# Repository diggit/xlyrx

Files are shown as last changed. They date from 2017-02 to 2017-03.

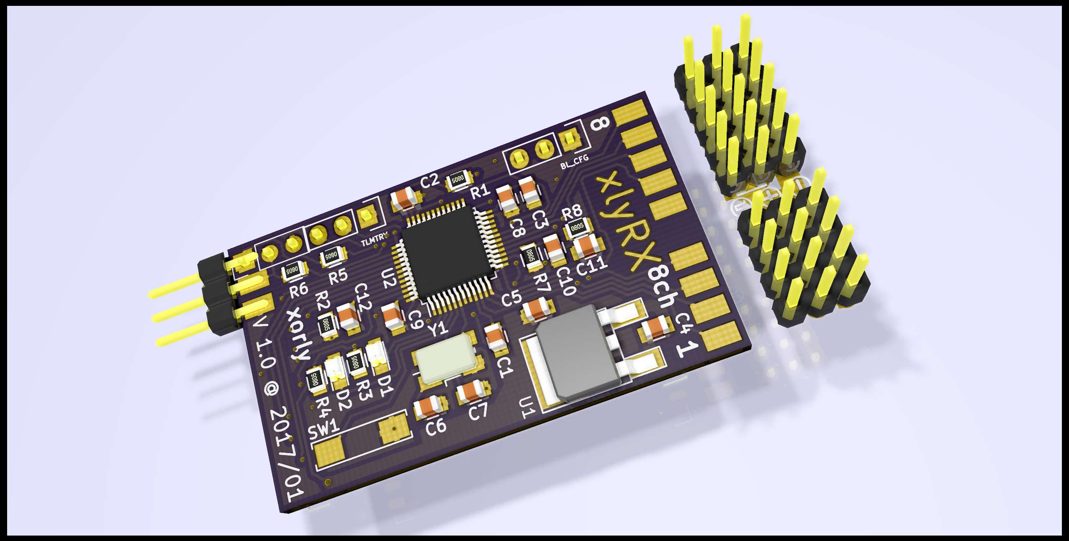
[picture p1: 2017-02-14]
design/pcb/xlyRX.png

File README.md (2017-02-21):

# xlyrx
Hobby RC 2.4GHz receiver based on cc2500 and STM32, supporting FrSky 2 Way D-series protocol

This project is another opensource receiver for cc2500 based radios.

## Features
- FrSky 2-way (telemetry) protocol for D-series
- based on ARM MCU (STM32)
- Hardware generated high resolution ppm signal (~4 times higher, than FrSky can tranfer)
- bind time RX-TX frequency offset elimination
- high power power amplifier and high sensitivity low noise amplifier cc2500 module
- alternative power input for channels 5,6,7,8
- 2 analog inputs
- initial work on fail-safes, when signal is lost, outputs are tuned off now, user config is missing

*ready, but hardcoded for now*
- configurable ppm frequency
	- channels 1,2,5,6 are driven by one HW timer, outputs 4,5,7,8 are driven by another
	- ppm frequency is defined by 3rd timer, all channels have same frequency for now, to be able to have different ppm frequency for each group, packet timeout timer must be changed from regular timer to systick, then we'll have free HW timer to drive second group of outputs with different frequency

*HW ready, SW not yet written*
- UART (3,3V) for loading new firmware (bootloader) and RX user configuration
- UART (3,3V) for external telemetry configuration (raw or FrSky format)
- meaningful usage of LED (we have 2 of them, so use them!)

### Known issues
- if TX and RX are too close during binding, binding may not be successful (stuck in binding mode)
	- maybe some AGC tuning could help
	- workaround would be binding procedure restart

## Why?
If you sum up all that time, materials and work, why (I) build this and not buy regular FrSky receiver? For fun! To explore HW, skills... I like the possibility to modify things to way I like them. Easily add new features and make them better than regular ones...

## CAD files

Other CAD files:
design/case/housing.fcstd

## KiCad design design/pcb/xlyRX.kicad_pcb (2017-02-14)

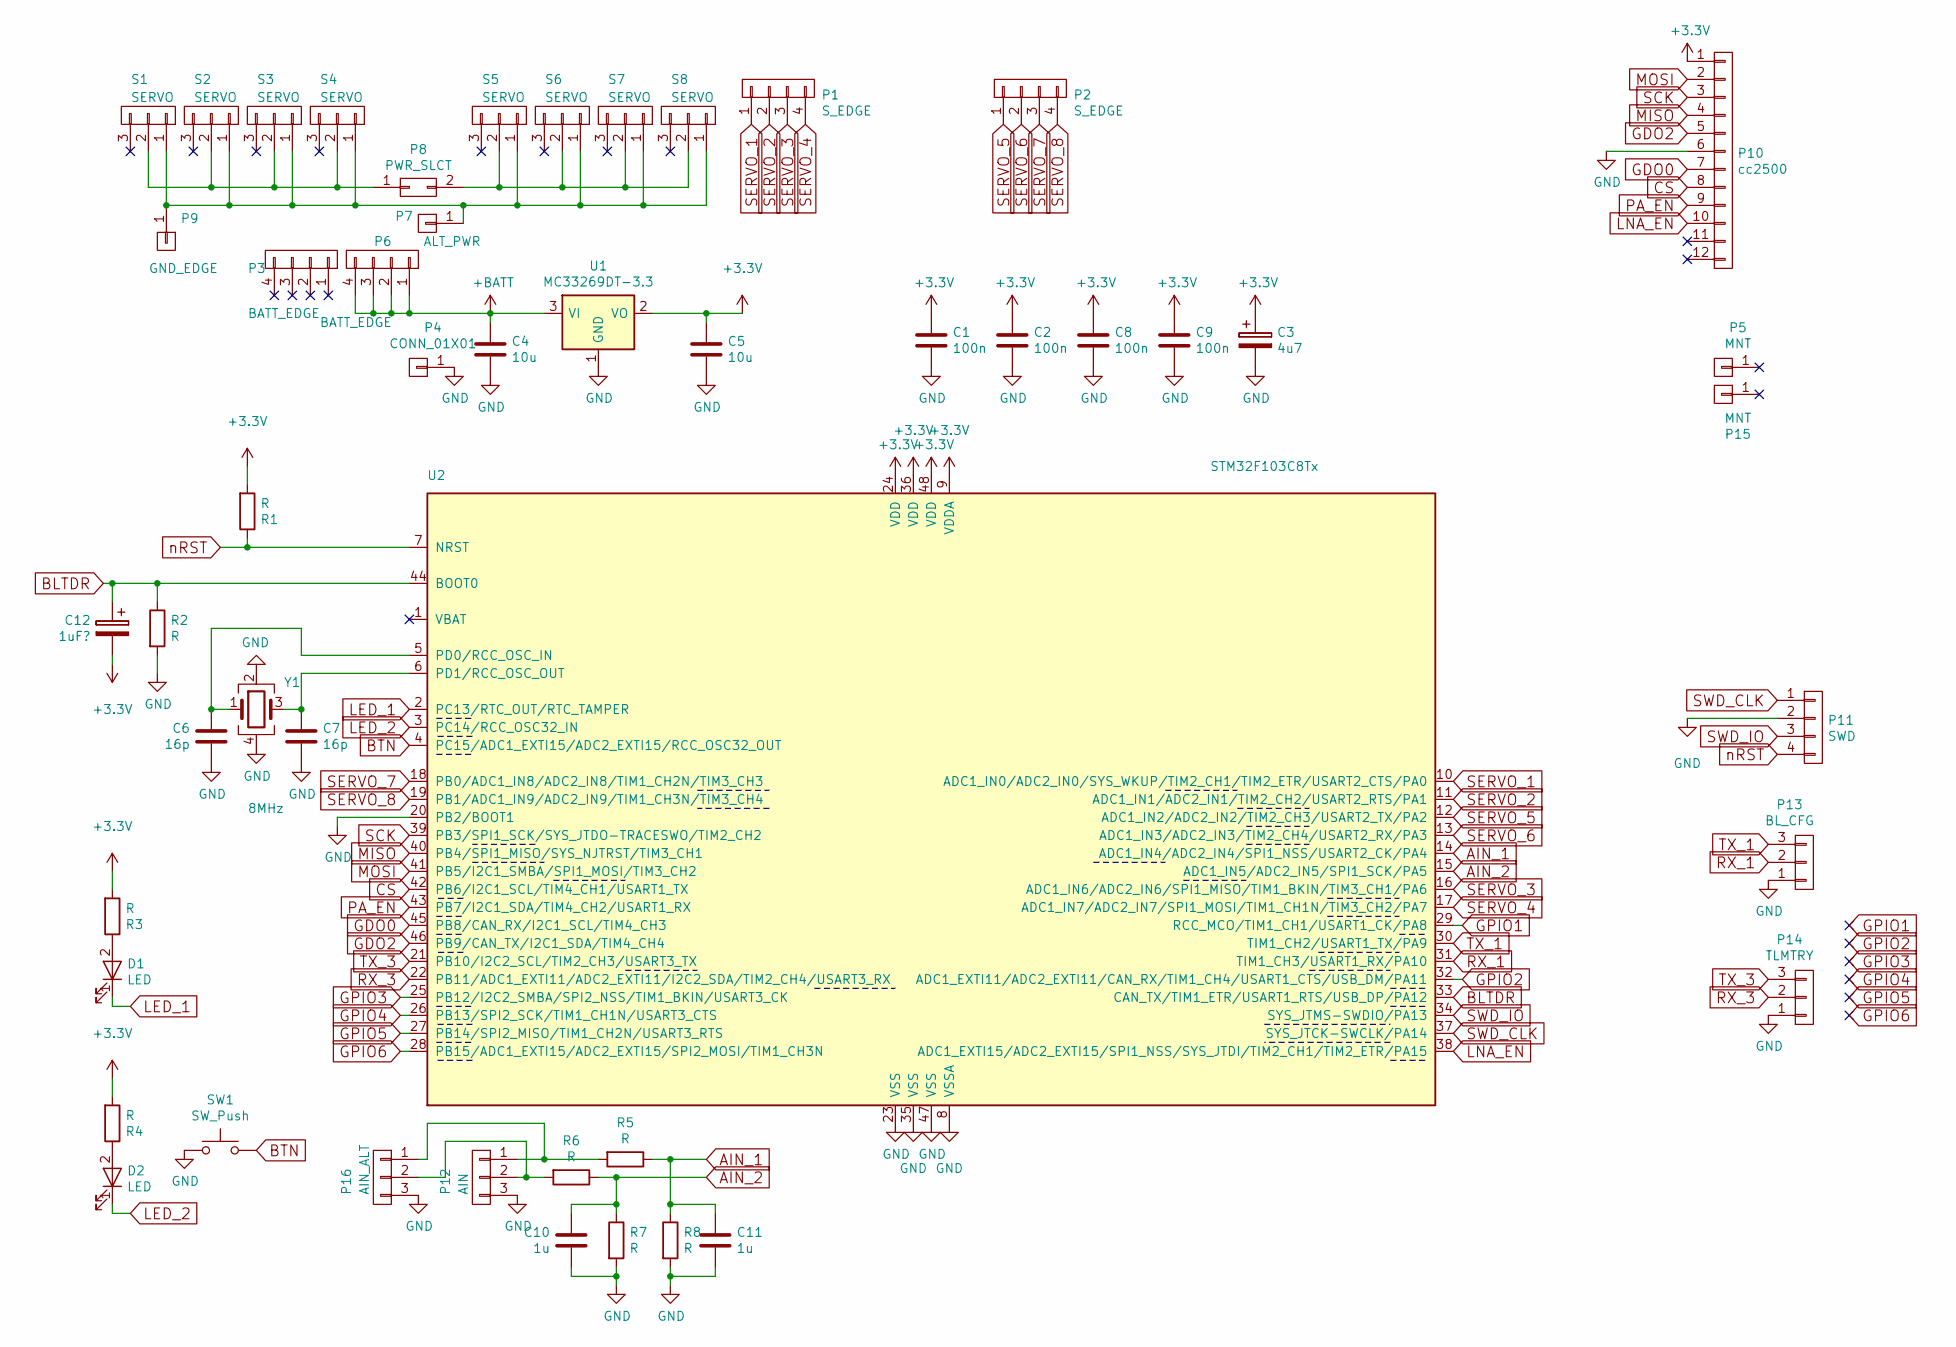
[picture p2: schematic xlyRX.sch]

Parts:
C1, C2, C8, C9: 100n; C_0805
C3: 4u7; C_0805
C4, C5: 10u; C_0805
C6, C7: 16p; C_0805
C10, C11: 1u; C_0805
C12: 1uF?; C_0805
D1, D2: LED; LED_0805
P1, P2: S_EDGE; SMD_conn_edge
P3, P6: BATT_EDGE; SMD_conn_edge
P4: CONN_01X01; SMD_conn_edge_1p
P5, P15: MNT; SMD_conn_edge_1p
P7: ALT_PWR; Pin_Header_Straight_1x01_Pitch2.54mm_simplified_silk
P8: PWR_SLCT; Pin_Header_Straight_1x02_Pitch2.54mm_simplified_silk
P9: GND_EDGE; SMD_conn_edge_1p
P10: cc2500; module_cc2500_PA_LNA_small_pads
P11: SWD; SMD_conn_edge
P12: AIN; SMD_conn_edge_3
P13: BL_CFG; Pin_Header_Straight_1x03
P14: TLMTRY; Pin_Header_Straight_1x03
P16: AIN_ALT; Pin_Header_Straight_1x03_Pitch2.54mm
R1, R2, R3, R4, R5, R6, R7, R8: R; R_0805
S1, S2, S3, S4, S5, S6, S7, S8: SERVO; Pin_Header_Straight_1x03_Pitch2.54mm_simplified_silk
SW1: SW_Push; SW_SPST_REED_CT05-XXXX-J1
U1: MC33269DT-3.3; TO-252-2Lead
U2: STM32F103C8Tx; LQFP-48_7x7mm_Pitch0.5mm
Y1: 8MHz; Crystal_SMD_5032_4Pads

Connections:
+3V3: C1.1, C2.1, C3.1, C5.1, C8.1, C9.1, C12.2, P10.1, R1.2, R3.2, R4.2, U1.2 (VO), U2.9 (VDDA), U2.24 (VDD), U2.36 (VDD), U2.48 (VDD)
+BATT: C4.1, P6.1, P6.2, P6.3, P6.4, U1.3 (VI)
AIN_1: C11.1, R5.1, R8.1, U2.14 (ADC1_IN4/ADC2_IN4/SPI1_NSS/USART2_CK/PA4)
AIN_2: C10.1, R6.1, R7.1, U2.15 (ADC1_IN5/ADC2_IN5/SPI1_SCK/PA5)
BLTDR: C12.1, R2.1, U2.33 (CAN_TX/TIM1_ETR/USART1_RTS/USB_DP/PA12), U2.44 (BOOT0)
BTN: SW1.2, U2.4 (PC15/ADC1_EXTI15/ADC2_EXTI15/RCC_OSC32_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)
CS: P10.8, U2.42 (PB6/I2C1_SCL/TIM4_CH1/USART1_TX)
GDO0: P10.7, U2.45 (PB8/CAN_RX/I2C1_SCL/TIM4_CH3)
GDO2: P10.5, U2.46 (PB9/CAN_TX/I2C1_SDA/TIM4_CH4)
GND: C1.2, C2.2, C3.2, C4.2, C5.2, C6.2, C7.2, C8.2, C9.2, C10.2, C11.2, P4.1, P10.6, P11.2, P12.3, P13.1, P14.1, P16.3, R2.2, R7.2, R8.2, SW1.1, U1.1 (GND), U2.8 (VSSA), U2.20 (PB2/BOOT1), U2.23 (VSS), U2.35 (VSS), U2.47 (VSS), Y1.2, Y1.4
GPIO1: U2.29 (RCC_MCO/TIM1_CH1/USART1_CK/PA8)
GPIO2: U2.32 (ADC1_EXTI11/ADC2_EXTI11/CAN_RX/TIM1_CH4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)
GPIO3: U2.25 (PB12/I2C2_SMBA/SPI2_NSS/TIM1_BKIN/USART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)
GPIO4: U2.26 (PB13/SPI2_SCK/TIM1_CH1N/USART3_CTS)
GPIO5: U2.27 (PB14/SPI2_MISO/TIM1_CH2N/USART3_RTS)
GPIO6: U2.28 (PB15/ADC1_EXTI15/ADC2_EXTI15/SPI2_MOSI/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)
LED_1: D1.1 (K), U2.2 (PC13/RTC_OUT/RTC_TAMPER)
LED_2: D2.1 (K), U2.3 (PC14/RCC_OSC32_IN)
LNA_EN: P10.10, U2.38 (ADC1_EXTI15/ADC2_EXTI15/SPI1_NSS/SYS_JT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)
MISO: P10.4, U2.40 (PB4/SPI1_MISO/SYS_NJTRST/TIM3_CH1)
MOSI: P10.2, U2.41 (PB5/I2C1_SMBA/SPI1_MOSI/TIM3_CH2)
unnamed: C6.1, U2.5 (PD0/RCC_OSC_IN), Y1.1
unnamed: C7.1, U2.6 (PD1/RCC_OSC_OUT), Y1.3
unnamed: D1.2 (A), R3.1
unnamed: D2.2 (A), R4.1
unnamed: P7.1, P9.1, S1.1, S2.1, S3.1, S4.1, S5.1, S6.1, S7.1, S8.1
unnamed: P8.1, S1.2, S2.2, S3.2, S4.2
unnamed: P8.2, S5.2, S6.2, S7.2, S8.2
unnamed: P12.1, P16.1, R5.2
unnamed: P12.2, P16.2, R6.2
PA_EN: P10.9, U2.43 (PB7/I2C1_SDA/TIM4_CH2/USART1_RX)
RX_1: P13.2, U2.31 (TIM1_CH3/USART1_RX/PA10)
RX_3: P14.2, U2.22 (PB11/ADC1_EXTI11/ADC2_EXTI11/I2C2_SDA/T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)
SCK: P10.3, U2.39 (PB3/SPI1_SCK/SYS_JTDO-TRACESWO/TIM2_CH2)
SERVO_1: P1.1, U2.10 (ADC1_IN0/ADC2_IN0/SYS_WKUP/TIM2_CH1/TIM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)
SERVO_2: P1.2, U2.11 (ADC1_IN1/ADC2_IN1/TIM2_CH2/USART2_RTS/P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)
SERVO_3: P1.3, U2.16 (ADC1_IN6/ADC2_IN6/SPI1_MISO/TIM1_BKIN/T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)
SERVO_4: P1.4, U2.17 (ADC1_IN7/ADC2_IN7/SPI1_MOSI/TIM1_CH1N/T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)
SERVO_5: P2.1, U2.12 (ADC1_IN2/ADC2_IN2/TIM2_CH3/USART2_TX/PA2)
SERVO_6: P2.2, U2.13 (ADC1_IN3/ADC2_IN3/TIM2_CH4/USART2_RX/PA3)
SERVO_7: P2.3, U2.18 (PB0/ADC1_IN8/ADC2_IN8/TIM1_CH2N/TIM3_CH3)
SERVO_8: P2.4, U2.19 (PB1/ADC1_IN9/ADC2_IN9/TIM1_CH3N/TIM3_CH4)
SWD_CLK: P11.1, U2.37 (SYS_JTCK-SWCLK/PA14)
SWD_IO: P11.3, U2.34 (SYS_JTMS-SWDIO/PA13)
TX_1: P13.3, U2.30 (TIM1_CH2/USART1_TX/PA9)
TX_3: P14.3, U2.21 (PB10/I2C2_SCL/TIM2_CH3/USART3_TX)
nRST: P11.4, R1.1, U2.7 (NRST)

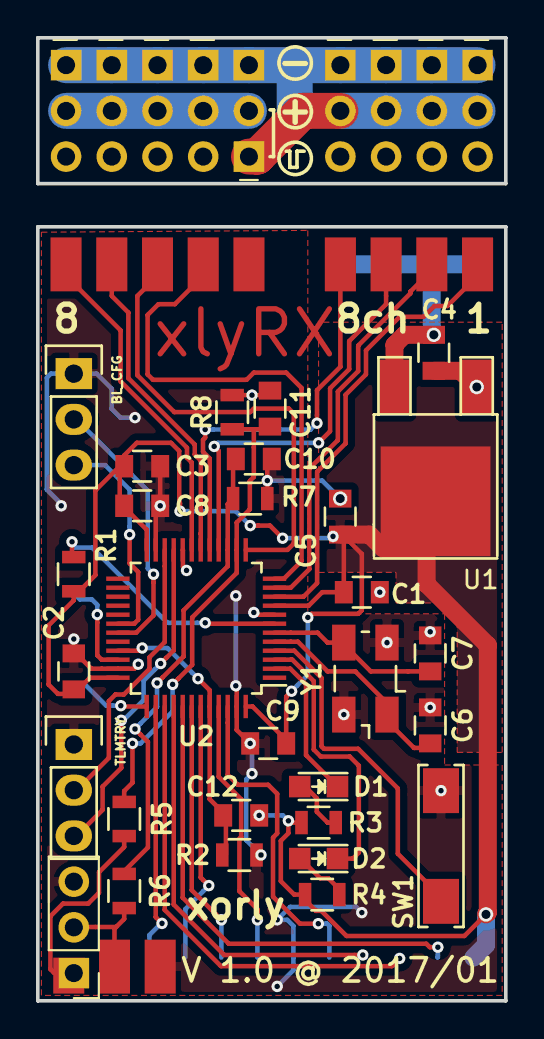
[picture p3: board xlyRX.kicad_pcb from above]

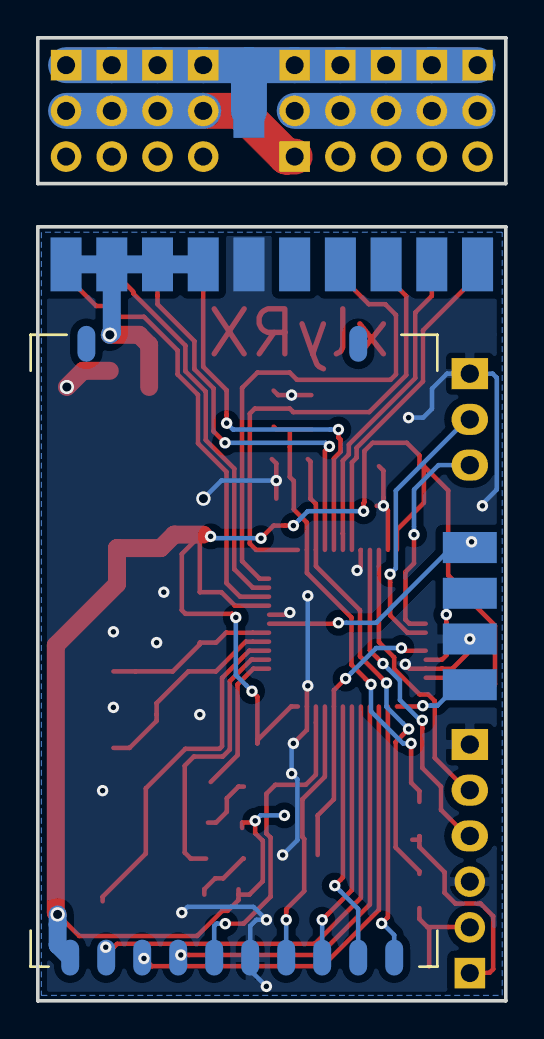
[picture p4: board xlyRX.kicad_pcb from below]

Board: 2 copper layers, 26.0 x 53.5 mm, 50 parts (7 on the bottom side), 41 nets.

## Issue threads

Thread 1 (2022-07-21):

Getting stucked in calibration

satyagupta, 2022-07-21:
Thanks for this fantastic code base. I am trying to rebuild a diy frsky receiver based on your frimware. Based on very little documentation and resources for CC2500 i really appreciate the efforts you have taken to write this firmware.

What is happening right now, is the moment interrupt is attached on the GD0 pin while calibrating the mcu gets stucked in the callback.

While checking on oscilloscope 2500 takes some time from going to idel to scal and during this the GD0 generates a square wave of very high freuqency, which is causing this.

Any pointers how to get around this? Is there any way we can connect via email/discorrd/slack. I really need some guidance help on this to get it working.

TIA

diggit, 2022-07-29:
Hi,
I am not sure I'll be able to help. This project i 5 years old any all knowledge of CC2500 or FrSky (D?) protocol is no longer in my head. I never has issue with spammed IRQ pin as much as I remember. If it's not described in datasheet of CC2500, I'd guess it's something like missing pull-up or so.

You might be interested in project [DIY-Multiprotocol-TX-Module](https://github.com/pascallanger/DIY-Multiprotocol-TX-Module).
It's still active and most probably working better.

satyagupta, 2022-07-29:
Yea i checked that too but its too confusing and based on arduino or around it. I want it for a ARM mcu

Thanks for responding on this :) i really appreciate your reply

diggit, 2022-07-29:
Yeah, I am also not a big fan of Arduino based projects. Despite that, Arduino is basically C++, easy to manage libraries and one (too)simple code editor. It also supports ARM base MCUs. I am not telling you to switch to Arduino, just use it as guidance in your journey.
BTW, I switched to C++, CMake and VScode (cortex-debug) combo sometime ago.

satyagupta, 2022-07-29:
I am planning to do the move :)
Please share any resources if you have :)

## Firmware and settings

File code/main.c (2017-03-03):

// Copyright (c) 2017 Patrik Bachan
//
// GNU GENERAL PUBLIC LICENSE
//    Version 3, 29 June 2007
//
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
#include "stm32f103xb.h"
#include "misc.h"
#include "uart.h"
#include "spi.h"
#include "cc2500.h"
#include "protocol.h"
#include "irq.h"
#include "timers.h"
#include "flash.h"
#include "hardware.h"
#include "adc.h"
#include "systick.h"

#include <inttypes.h>


void system_clock_init(void)
{
	bit_set(RCC->CSR, RCC_CSR_LSION);//enable LSI for IWDG
	bit_set(FLASH->ACR, 1<<FLASH_ACR_LATENCY_Pos);//increase wait times for flash
	// led_flash(0);
	bit_clr(RCC->CR, RCC_CR_HSEON | RCC_CR_HSEBYP);//off ext OSC, off ext OSC bypass
	bit_set(RCC->CR, RCC_CR_HSEON);//reenable ext OSC
	while(bit_get(RCC->CR, RCC_CR_HSERDY)==0)//wait for OSC to settle
		NOP;

	RCC->CFGR = RCC_CFGR_PLLSRC | RCC_CFGR_PLLMULL9 | RCC_CFGR_PPRE1_DIV2 | RCC_CFGR_ADCPRE_DIV8;
	bit_set(RCC->CR, RCC_CR_PLLON);//enable PLL
	while(bit_get(RCC->CR, RCC_CR_PLLRDY)==0)//wat for PLL to stabilize
		NOP;
	// led_flash(0);
	bit_mod(RCC->CFGR, RCC_CFGR_SW_Msk, RCC_CFGR_SW_PLL);//set system clock soutce to PLL
	//bit_clr(RCC->CR, RCC_CR_HSION);//off HSI

}

void draw_bar(uint8_t length, uint8_t filled, uint8_t ch)
{
	uart_send_byte_blocking('[');
	uint8_t cursor;
	for(cursor=0; cursor<filled; cursor++)
		uart_send_byte_blocking(ch);
	for(;cursor<length; cursor++)
		uart_send_byte_blocking(' ');
	uart_send_byte_blocking(']');
}

void uart_handler(uint8_t data)
{
	if(data=='B')
	{
		led_on(HARDWARE_LED_2);
		irq_disable();
		GPIOA->BSRR=GPIO_BSRR_BS12;//charge capacitor on BL pin
		delay_ms(10);

		//reset using IDWG, I was not successful using system reset
		IWDG->KR=0xCCCCU;//start IWDG
		IWDG->KR=0x5555U;//enable access to prescaler and preload regs.
		IWDG->RLR=1;
		IWDG->PR=0;
		while(IWDG->SR!=0)
			NOP;
		IWDG->KR=0xAAAAU;//reload IWDG

		while(1)
			NOP;
	}

}


uint8_t fifo[64];

int main(void)
{
	system_clock_init();
	gpio_init();
	swdt_init();
	adc_init_single();
	adc_calibrate();

	systick_init();

	// systick_blink_set(HARDWARE_LED_2, 0, SYSTICK_1s*0.1);


	irq_enable();
	irq_NVIC_ISE(EXTI9_5_IRQn);

	led_on(HARDWARE_LED_2);

	uart_init(NULL);
	uart_rx_handler_set(uart_handler);
	// uart_send_string_blocking("\x1B[1J\x1B[;H");
	uart_send_string_blocking("\nxlyRX starting...\n");
	uart_send_string_blocking("Build: ");
	#ifdef BUILD
	uart_send_string_blocking(itoa(BUILD,3));
	uart_send_string_blocking(" @ ");
	#endif
	uart_send_string_blocking(__DATE__);
	uart_send_byte_blocking(' ');
	uart_send_string_blocking(__TIME__);
	uart_send_byte_blocking('\n');

	spi_init(3);
	ppm_init();
	protocol_frsky_start(button_read());


	// led1_flash(100);

	while(1)
	{
		NOP;
	}
}

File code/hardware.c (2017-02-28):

// Copyright (c) 2017 Patrik Bachan
//
// GNU GENERAL PUBLIC LICENSE
//    Version 3, 29 June 2007
//
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
#include "hardware.h"
#include "misc.h"


void gpio_init(void)
{
	bit_set(RCC->APB2ENR, \
			RCC_APB2ENR_IOPAEN |\
			RCC_APB2ENR_IOPBEN |\
			RCC_APB2ENR_IOPCEN |\
			RCC_APB2ENR_AFIOEN);// enable clock to ports A,B,C, USART1, AFIO

	AFIO->MAPR =	AFIO_MAPR_SPI1_REMAP | AFIO_MAPR_SWJ_CFG_JTAGDISABLE;

	GPIOA->CRL =	\
					//PA0	S0	(TIM2_CH1)
					GPIO_ALTERNATE			<<GPIO_CRL_MODE0_Pos|\
					//PA1	S1	(TIM2_CH2)
					GPIO_ALTERNATE			<<GPIO_CRL_MODE1_Pos|\
					//PA2	S5	(TIM2_CH3)
					GPIO_ALTERNATE			<<GPIO_CRL_MODE2_Pos|\
					//PA3	S6	(TIM2_CH4)
					GPIO_ALTERNATE			<<GPIO_CRL_MODE3_Pos|\
					//PA4	AIN_1	(ADC_IN4)
					GPIO_INPUT_ANALOG		<<GPIO_CRL_MODE4_Pos|\
					//PA5	AIN_2	(ADC_IN5)
					GPIO_INPUT_ANALOG		<<GPIO_CRL_MODE5_Pos|\
					//PA6	S3	(TIM3_CH1)
					GPIO_ALTERNATE			<<GPIO_CRL_MODE6_Pos|\
					//PA7	S4	(TIM3_CH2)
					GPIO_ALTERNATE			<<GPIO_CRL_MODE7_Pos;

	GPIOA->CRH = 	\
					//PA8	GPIO1	(GPIO)
					GPIO_INPUT				<<GPIO_CRH_MODE8_Pos|\
					//PA9	BL_FG_TX	(USART1_TX)
					GPIO_ALTERNATE			<<GPIO_CRH_MODE9_Pos|\
					//PA10	BL_FG_RX	(USART1_RX)
					GPIO_INPUT_PULL_UP_DOWN	<<GPIO_CRH_MODE10_Pos|\
					//PA11	GPIO2	(GPIO)
					GPIO_INPUT				<<GPIO_CRH_MODE11_Pos|\
					//PA12	BTLDR	(GPIO)
					GPIO_OUTPUT				<<GPIO_CRH_MODE12_Pos|\
					/*SWD
					GPIO_INPUT				<<GPIO_CRH_MODE13_Pos|\
					GPIO_INPUT				<<GPIO_CRH_MODE14_Pos|\
					*/
					//PA15	LNA_EN	(GPIO)
					GPIO_OUTPUT				<<GPIO_CRH_MODE15_Pos;

	GPIOA->ODR =	\
					//PA10 PUP
					GPIO_ODR_ODR10;

	GPIOB->CRL =	\
					//PB0	S7		(TIM3_CH3)
					GPIO_ALTERNATE			<<GPIO_CRL_MODE0_Pos|\
					//PB1	S8		(TIM3_CH4)
					GPIO_INPUT				<<GPIO_CRL_MODE1_Pos|\
					//PB2	BOOT1
					/*GPIO_INPUT				<<GPIO_CRL_MODE2_Pos|\*/
					//PB3	SCK		(SPI1_SCK) REMAP!
					GPIO_ALTERNATE_10MHz	<<GPIO_CRL_MODE3_Pos|\
					//PB4	MISO	(SPI1_MISO) REMAP!
					GPIO_INPUT				<<GPIO_CRL_MODE4_Pos|\
					//PB5	MOSI	(SPI1_MOSI) REMAP!
					GPIO_ALTERNATE_10MHz	<<GPIO_CRL_MODE5_Pos|\
					//PB6	CS		(GPIO)
					GPIO_OUTPUT_2MHz		<<GPIO_CRL_MODE6_Pos|\
					//PB7	PA_EN	(GPIO)
					GPIO_OUTPUT				<<GPIO_CRL_MODE7_Pos;

	GPIOB->CRH = 	\
					//PB8	GDO0	(GPIO)
					GPIO_INPUT				<<GPIO_CRH_MODE8_Pos|\
					//PB9	GDO2	(GPIO)
					GPIO_INPUT				<<GPIO_CRH_MODE9_Pos|\
					//PB10	TLMTRY_TX	(USART3_TX)
					GPIO_ALTERNATE			<<GPIO_CRH_MODE10_Pos|\
					//PB11	TLMTRY_RX	(USART3_RX)
					GPIO_INPUT_PULL_UP_DOWN	<<GPIO_CRH_MODE11_Pos|\
					//PB12	GPIO3	(GPIO)
					GPIO_INPUT				<<GPIO_CRH_MODE12_Pos|\
					//PB13	GPIO4	(GPIO)
					GPIO_INPUT				<<GPIO_CRH_MODE13_Pos|\
					//PB14	GPIO5	(GPIO)
					GPIO_INPUT				<<GPIO_CRH_MODE14_Pos|\
					//PB15	GPIO6	(GPIO)
					GPIO_INPUT				<<GPIO_CRH_MODE15_Pos;

	GPIOB->ODR =	\
					//PB6	HIGH
					GPIO_ODR_ODR6|\
					//PB11	PUP
					GPIO_ODR_ODR11;

	//only pins 13,14,15 present
	GPIOC->CRH = 	\
					//PC13	LED_1	(GPIO)
					GPIO_OUTPUT				<<GPIO_CRH_MODE13_Pos|\
					//PC14	LED_2	(GPIO)
					GPIO_OUTPUT				<<GPIO_CRH_MODE14_Pos|\
					//PC15	BTN		(GPIO)
					GPIO_INPUT_PULL_UP_DOWN	<<GPIO_CRH_MODE15_Pos;

	GPIOC->ODR =	\
					//PC13	LED(OFF)
					GPIO_ODR_ODR13|\
					//PC14	LED(OFF)
					GPIO_ODR_ODR14|\
					//PC15	BTN PUP
					GPIO_ODR_ODR15;


	//enable EXTI inttterupt for GDOs
	AFIO->EXTICR[2]=AFIO_EXTICR3_EXTI8_PB | AFIO_EXTICR3_EXTI9_PB;
}

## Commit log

2017-02-14 initial sources and design commit
    [housing.fcstd, stm32f1xx_ftdi_swd.cfg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]
2017-02-14 pcb development version
    [xlyRX.kicad_pcb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]
2017-02-15 reload all KiCAD symbol libraries
2017-02-21 improve TX timing (interrupt driven), release outputs on signal loss (initial fail-safe work)
    [protocol.c, protocol.h, timers.c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]
2017-02-21 update README (fail-safe, LEDs)
2017-02-25 change cc2500 LNA/PA switching commands order to give at least some deadtime
2017-02-25 add systick(non blocking) LED blink functionality
2017-02-28 add ability to read button state
2017-03-03 fix button state polarity
2017-03-03 add reset by uart
    [main.c, uart.c]
2017-03-03 add led status indication, tune cc2500 settings, 100m range tested - works well
2017-03-03 modify ftdi config to be able to set n?RST outputs to Hi-z
    [stm32f1xx_ftdi_swd.cfg]
2017-03-03 add systick button handling (untested)
2017-07-14 set PPM frequency to 200Hz, fix const
    [config.c, config.h]
2017-07-15 rename currently supported protocol from 2W to D
2017-07-15 fix all protocol renaming from 2W to D, rename BIND constants to protocol specific names
    [protocol.c, protocol.h]

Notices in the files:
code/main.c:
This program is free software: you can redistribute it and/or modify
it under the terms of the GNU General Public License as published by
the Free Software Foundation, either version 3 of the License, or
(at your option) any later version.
